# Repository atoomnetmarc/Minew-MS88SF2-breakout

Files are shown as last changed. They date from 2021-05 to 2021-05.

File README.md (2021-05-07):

This is a simple breakout board for the nRF52840 Minew MS88SF2 module.

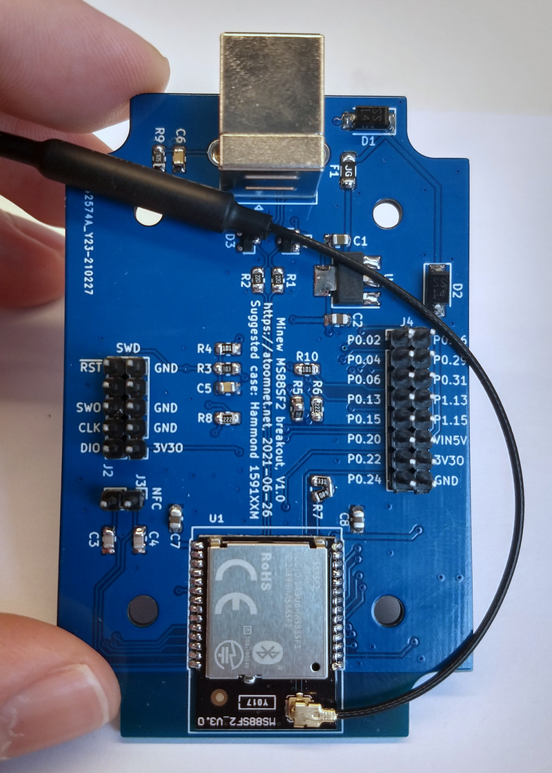
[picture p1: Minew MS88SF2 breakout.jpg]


# Assembly instructions

Solder all components except the module. Clean PCB.

Test if 3V3 regulator works by connecting 5V to VIN5V-pin (with 50mA power limit). The board should not use any significant current. Measure the 3V3O-pin, it should be 3.3V.

Now solder module.

Do not forget to connect an antenna if using the MS88SF2-U.FL module.

# Checklist (WIP) V1.0 PCB

Testing and working? (after bodge fix, see V1.1 changelog)

:ballot_box_with_check:SWD (SWDIO, SWCLK, SWO)\
:ballot_box_with_check:RESET (P0.18)\
:ballot_box_with_check:USB\
:black_square_button:NFC (P0.09, P0.10)\
:black_square_button:P0.02\
:black_square_button:P0.04\
:ballot_box_with_check:LED green (P0.06)\
:black_square_button:LED RGB red (P0.08)\
:ballot_box_with_check:LED RGB blue (P0.12)\
:black_square_button:P0.13\
:black_square_button:P0.15\
:black_square_button:P0.20\
:black_square_button:P0.22\
:black_square_button:P0.24\
:black_square_button:P0.26\
:black_square_button:P0.29\
:black_square_button:P0.31\
:ballot_box_with_check:LED RGB green (P1.09)\
:black_square_button:Button (P1.13)\
:black_square_button:P1.15

# Changelog

**V1.1**

- Attached VDDH to VBUS to enable USB to work.
- Removed series resistors from USB data lines.

**V1.0**

- Everything changed out of nothing.



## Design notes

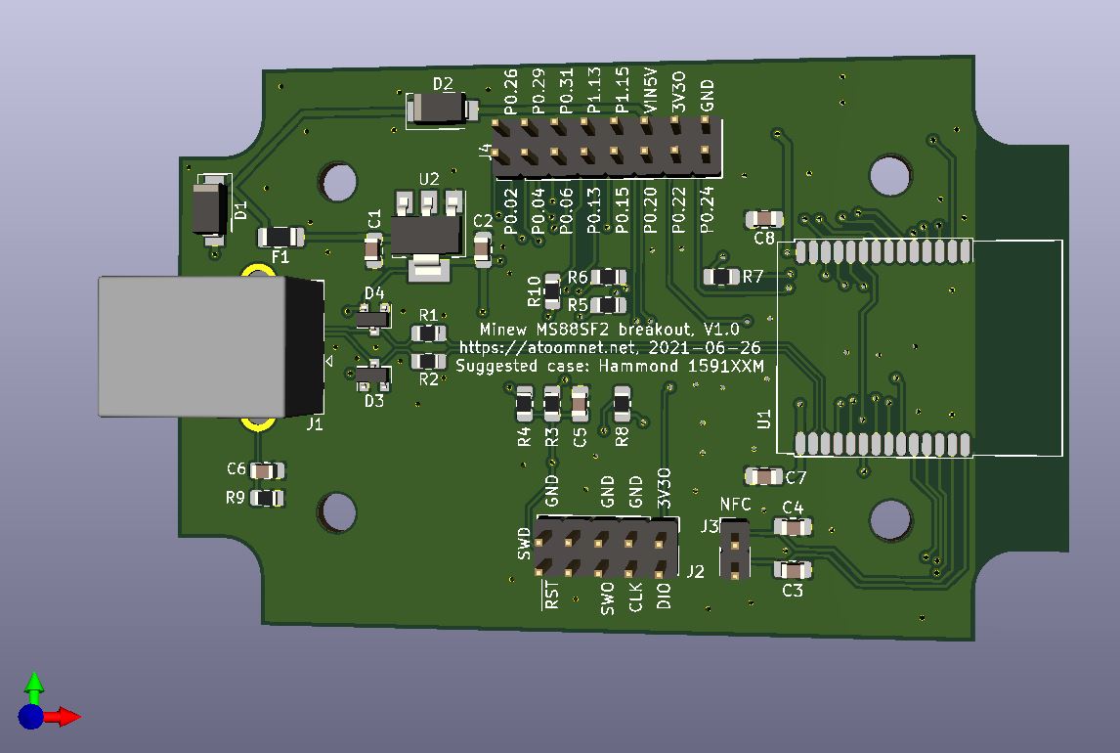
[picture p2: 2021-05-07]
Minew MS88SF2 breakout-render.jpg

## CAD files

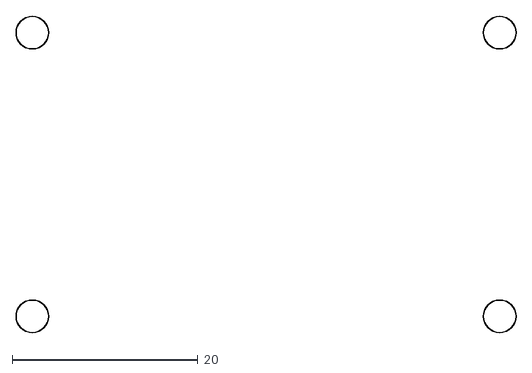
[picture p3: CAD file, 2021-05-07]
Hammond 1591XXM pcb-holes.dxf
53.8 x 34.0

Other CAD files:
Hammond 1591XXM pcb outline.FCStd
Hammond 1591XXM pcb-outline.dxf

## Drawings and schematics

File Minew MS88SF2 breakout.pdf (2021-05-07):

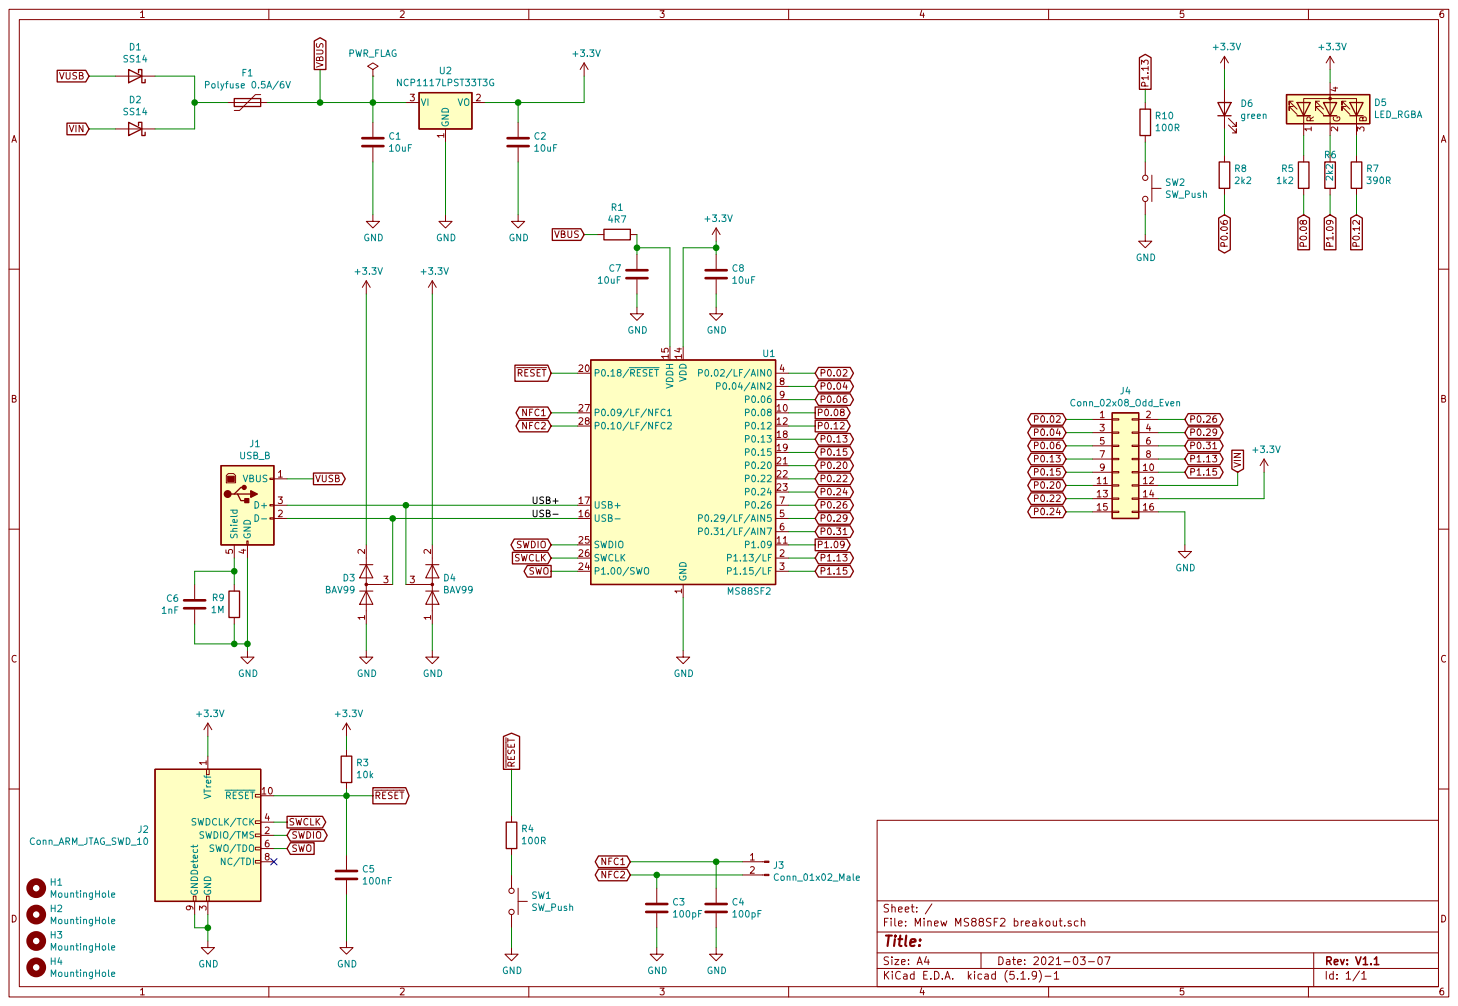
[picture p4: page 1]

1 P0.08 10 P1.09 11 P0.12 12 VDD 14 VDDH 15 USB- 16 USB+ 17 P0.13 18 P0.15 19 P1.13/LF 2 P0.18/RESET 20 P0.20 21 P0.22 22 P0.24 23 P1.00/SWO 24 SWDIO 25 SWCLK 26 P0.09/LF/NFC1 27 P0.10/LF/NFC2 28 P1.15/LF 3 P0.02/LF/AIN0 4 P0.29/LF/AIN5 5 P0.31/LF/AIN7 6 P0.26 7 P0.04/AIN2 8 P0.06 9 U1 MS88SF2 VBUS 1 D- 2 D+ 3 GND

Id: 1/1 Title: File: Minew MS88SF2 breakout.sch Sheet: / GND

3 SWDCLK/TCK 4 SWO/TDO 6 NC/TDI 8 GNDDetect 9

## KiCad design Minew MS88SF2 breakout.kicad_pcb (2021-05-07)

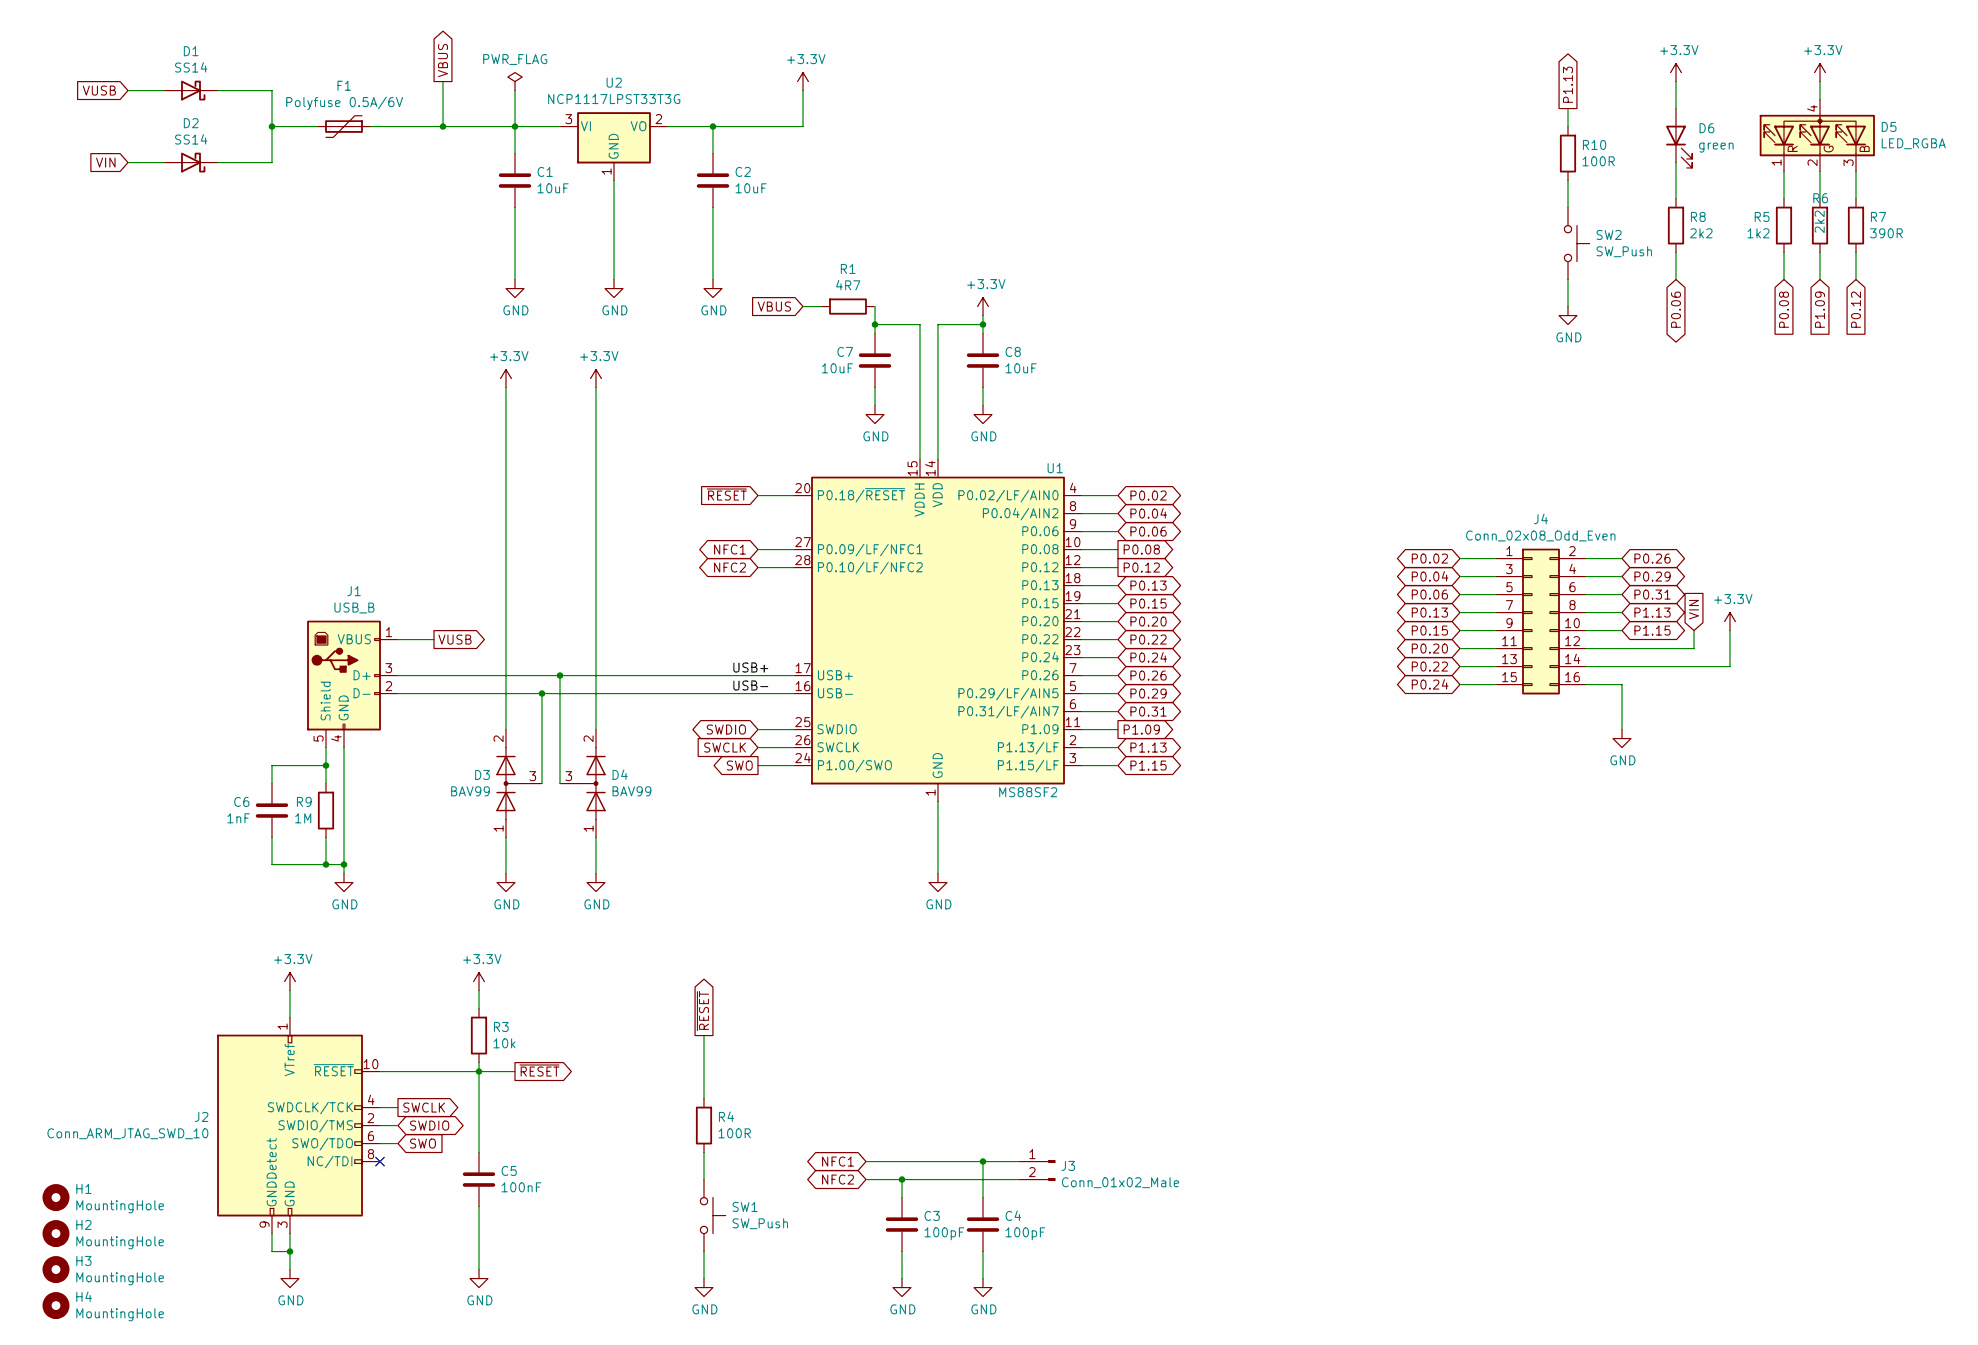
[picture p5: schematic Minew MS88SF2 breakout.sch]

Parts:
C1, C2, C7, C8: 10uF; C_0805_2012Metric_Pad1.18x1.45mm_HandSolder
C3, C4: 100pF; C_0805_2012Metric_Pad1.18x1.45mm_HandSolder
C5: 100nF; C_0805_2012Metric_Pad1.18x1.45mm_HandSolder
C6: 1nF; C_0805_2012Metric_Pad1.18x1.45mm_HandSolder
D1, D2: SS14; D_SMA
D3, D4: BAV99; SOT-23
D5: LED_RGBA; LED_RGB_3528
D6: green; LED_0805_2012Metric_Pad1.15x1.40mm_HandSolder
F1: Polyfuse 0.5A/6V; Fuse_1206_3216Metric_Pad1.42x1.75mm_HandSolder
H1, H2, H3, H4: MountingHole; MountingHole_3.5mm
J1: USB_B; USB_B_OST_USB-B1HSxx_Horizontal
J2: Conn_ARM_JTAG_SWD_10; PinHeader_2x05_P2.54mm_Vertical
J3: Conn_01x02_Male; PinHeader_1x02_P2.54mm_Vertical
J4: Conn_02x08_Odd_Even; PinHeader_2x08_P2.54mm_Vertical
R1: 4R7; R_0805_2012Metric_Pad1.20x1.40mm_HandSolder
R3: 10k; R_0805_2012Metric_Pad1.20x1.40mm_HandSolder
R4, R10: 100R; R_0805_2012Metric_Pad1.20x1.40mm_HandSolder
R5: 1k2; R_0805_2012Metric_Pad1.20x1.40mm_HandSolder
R6, R8: 2k2; R_0805_2012Metric_Pad1.20x1.40mm_HandSolder
R7: 390R; R_0805_2012Metric_Pad1.20x1.40mm_HandSolder
R9: 1M; R_0805_2012Metric_Pad1.20x1.40mm_HandSolder
SW1, SW2: SW_Push; SW_SPST_CK_RS282G05A3
U1: MS88SF2; MS88SF2-handsolder
U2: NCP1117LPST33T3G; SOT-223-3_TabPin2

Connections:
+3V3: C2.1, C8.1, D3.2 (A), D4.2 (A), D5.4 (A), D6.2 (A), J2.1 (VTref), J4.14, R3.2, U1.14 (VDD), U2.2 (VO)
/USB+: D4.3 (K), J1.3 (D+), U1.17 (USB+)
/USB-: D3.3 (K), J1.2 (D-), U1.16 (USB-)
GND: C1.2, C2.2, C3.2, C4.2, C5.2, C6.2, C7.2, C8.2, D3.1 (K), D4.1 (K), J1.4 (GND), J2.3 (GND), J2.5 (GND), J2.9 (GNDDetect), J4.16, R9.1, SW1.2, SW2.2, U1.1 (GND), U1.13 (GNDA), U2.1 (GND)
NFC1: C4.1, J3.1, U1.27 (P0.09/LF/NFC1)
NFC2: C3.1, J3.2, U1.28 (P0.10/LF/NFC2)
unnamed: C6.1, J1.5 (Shield), R9.2
unnamed: C7.1, R1.1, U1.15 (VDDH)
unnamed: D1.1 (K), D2.1 (K), F1.2
unnamed: D5.1 (RK), R5.2
unnamed: D5.2 (GK), R6.2
unnamed: D5.3 (BK), R7.2
unnamed: D6.1 (K), R8.2
unnamed: R4.1, SW1.1
unnamed: R10.1, SW2.1
P0.02: J4.1, U1.4 (P0.02/LF/AIN0)
P0.04: J4.3, U1.8 (P0.04/AIN2)
P0.06: J4.5, R8.1, U1.9 (P0.06)
P0.08: R5.1, U1.10 (P0.08)
P0.12: R7.1, U1.12 (P0.12)
P0.13: J4.7, U1.18 (P0.13)
P0.15: J4.9, U1.19 (P0.15)
P0.20: J4.11, U1.21 (P0.20)
P0.22: J4.13, U1.22 (P0.22)
P0.24: J4.15, U1.23 (P0.24)
P0.26: J4.2, U1.7 (P0.26)
P0.29: J4.4, U1.5 (P0.29/LF/AIN5)
P0.31: J4.6, U1.6 (P0.31/LF/AIN7)
P1.09: R6.1, U1.11 (P1.09)
P1.13: J4.8, R10.2, U1.2 (P1.13/LF)
P1.15: J4.10, U1.3 (P1.15/LF)
SWCLK: J2.4 (SWDCLK/TCK), U1.26 (SWCLK)
SWDIO: J2.2 (SWDIO/TMS), U1.25 (SWDIO)
SWO: J2.6 (SWO/TDO), U1.24 (P1.00/SWO)
VBUS: C1.1, F1.1, R1.2, U2.3 (VI)
VIN: D2.2 (A), J4.12
VUSB: D1.2 (A), J1.1 (VBUS)
~RESET: C5.1, J2.10 (~RESET~), R3.1, R4.2, U1.20 (P0.18/~RESET)

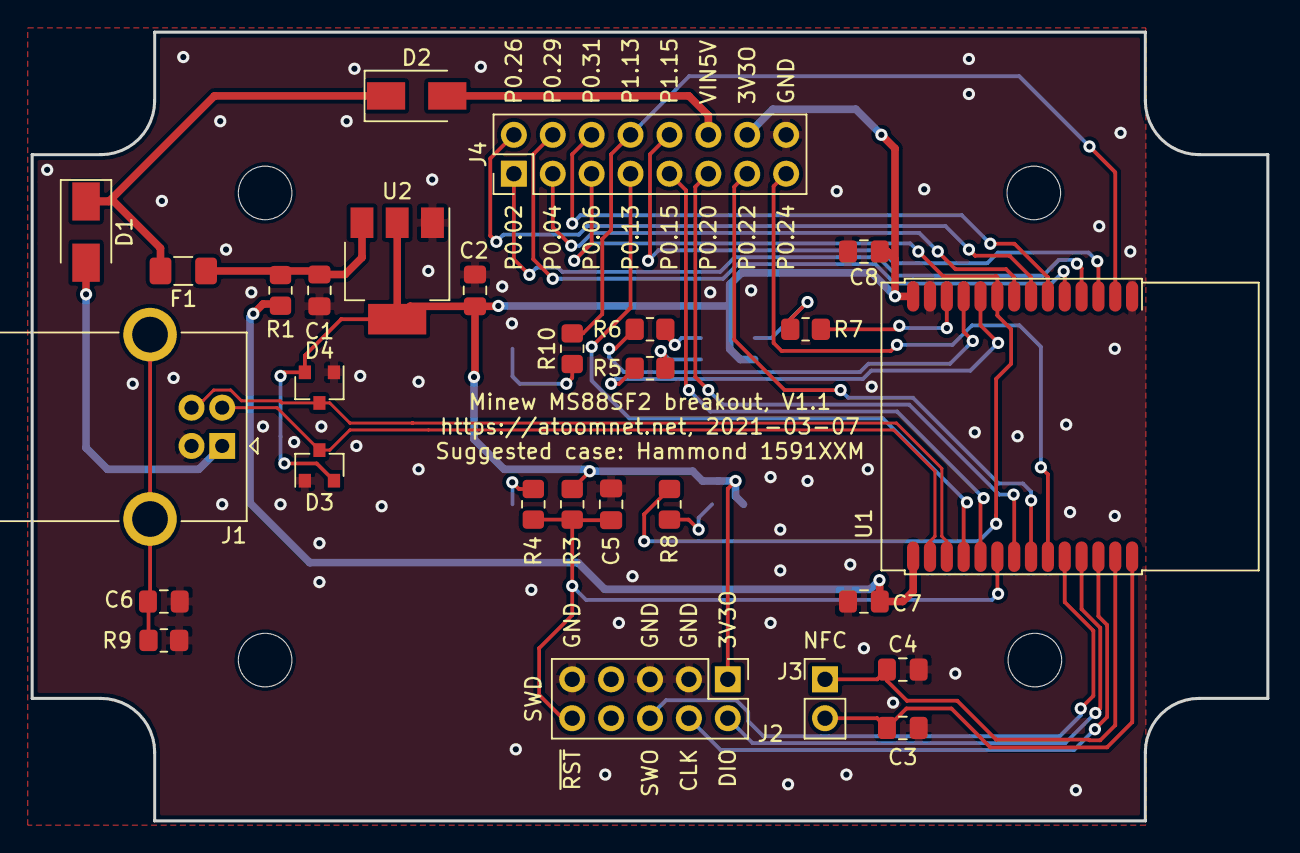
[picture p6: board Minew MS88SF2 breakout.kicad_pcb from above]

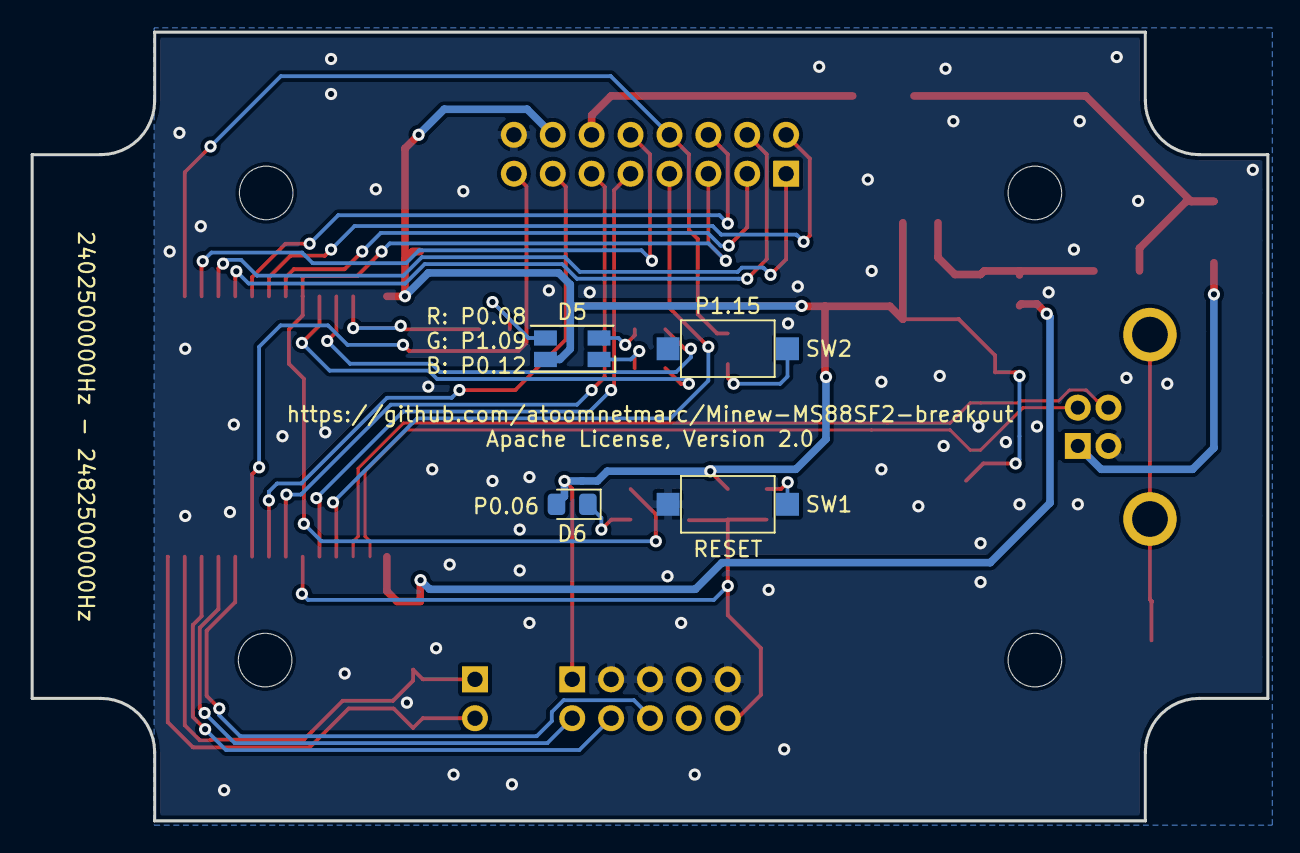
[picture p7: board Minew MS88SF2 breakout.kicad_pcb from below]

Board: 2 copper layers, 80.7 x 51.5 mm, 36 parts (4 on the bottom side), 38 nets.

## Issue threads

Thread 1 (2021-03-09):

Is the breakout confirmed working?

MangoIV, 2021-03-09:
Hi! I would like to ask, whether the breakout works, including USB. Thanks in advance.

atoomnetmarc, 2021-03-09:
I do not know if everything works. I have not tested it yet.

What I have tested on the V1.0 PCB is JTAG, that works. Some LEDs I have seen flashing. The reset button works (if you enable it). But the user-button and all other pins I have not tested.\
USB did not work on V1.0, but after mounting a bodge wire (VDDH was connected to VDD, but should be connected to 5V), USB started working and after programming a UF2 bootloader I was able drag firmware to the module. In this case it was the FTD variant of the OpenThread project. I was able to connect to my border router.\
The bodge wire resulted in a V1.1 PCB, but I have not made that PCB to validate.

TL;DR: I am not aware of any bugs in V1.1, but I have not tested everything.

MangoIV, 2021-03-09:
So basically if I have the VDDH connected to 5V over the R2 resistor as in configuration 1 in the datasheet, USB works and the module itself generally comes alive?

MangoIV, 2021-03-09:
Thanks a lot for your long answer :)

atoomnetmarc, 2021-03-09:
Added test checklist to README.md https://github.com/atoomnetmarc/Minew-MS88SF2-breakout/commit/54cf1dcff473c9ce5b2402c0c0bcd90490e8f438

MangoIV, 2021-03-09:
Thanks a lot! I was mainly concerned whether the module was going to come on on USB because the possible configurations aren't well described in the data sheet. Now I guess I'll have to try myself whether it also comes on on battery. Thanks a lot for your patience ;)

Closed 2021-03-09.

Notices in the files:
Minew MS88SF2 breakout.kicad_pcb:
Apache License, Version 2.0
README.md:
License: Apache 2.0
